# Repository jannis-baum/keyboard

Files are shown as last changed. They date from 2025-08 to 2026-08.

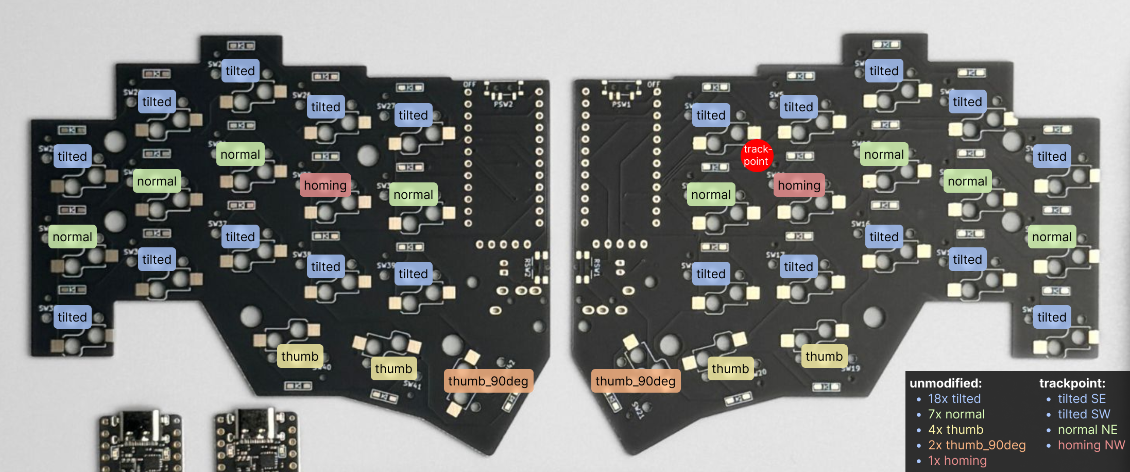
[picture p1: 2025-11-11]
hardware/keycaps/layout.png

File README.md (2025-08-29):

# Keyboard setup

I use a 36 key [Chocofi](https://github.com/pashutk/chocofi) keyboard with a [Sprintek SK8707-01 trackpoint](https://www.sprintek.com/en/products/pointing_stick/SK8707-01.aspx), made wireless with [nice!nano's](https://nicekeyboards.com/nice-nano).

This repo is where I keep my [ZMK firmware](https://zmk.dev) as well as my [Karabiner Elements](https://karabiner-elements.pqrs.org/) setup, and also the files to print the keyboard case & key caps.
Since I like having all my keybindings available on my laptop's built-in keyboard as well, most of the interesting stuff is implemented with Karabiner rather than ZMK.

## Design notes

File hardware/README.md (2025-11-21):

# Hardware parts

- printed:
    - keycaps are [KLP Lamé](https://github.com/braindefender/KLP-Lame-Keycaps/blob/76b0aec08eb0d98ea8802d6bd8cab8d96e1ae3f5), see [`LICENSE-keycaps`](LICENSE-keycaps)
    - case is derived from [official Chocofi case](https://github.com/pashutk/chocofi/blob/273676d11b06785fb5a1a94860a39fc36c38baba/case/v1/), see [`LICENSE-case`](LICENSE-case)
    - trackpoint extension is from [infused-kim/kb_trackpoint_extension](https://github.com/infused-kim/kb_trackpoint_extension/blob/6a5e8eec101584ba189b6014e04a38ebcbd04d82), see [`LICENSE-trackpoint-extension`](LICENSE-trackpoint-extension)
- electronics:
    - [Chocofi kit from beekeeb](https://shop.beekeeb.com/products/chocofi-low-profile-split-keyboard-diy-kit-nice-nano-wireless)
    - [SK8707-01 Trackpoint Sensor](https://www.sprintek.com/en/products/pointing_stick/SK8707-01.aspx)
    - [custom trackpoint connector PCB](./trackpoint-connector.zip)

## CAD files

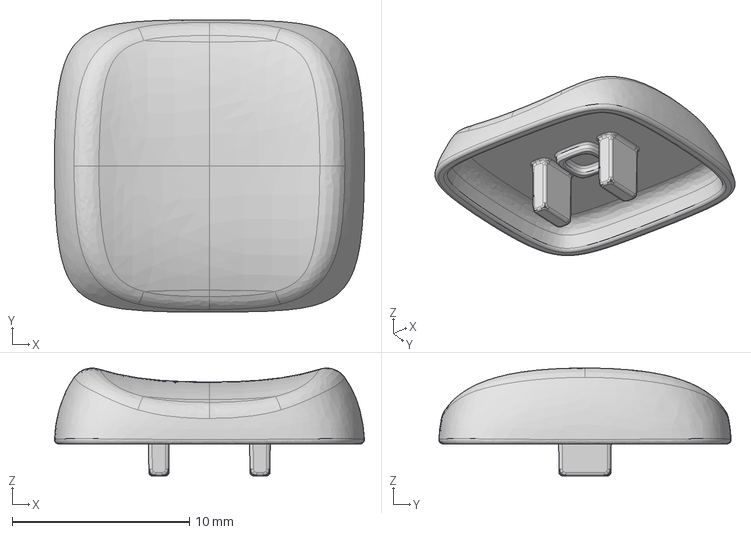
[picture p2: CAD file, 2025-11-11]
hardware/keycaps/step/normal.step
17.5 x 16.5 x 6.08 mm

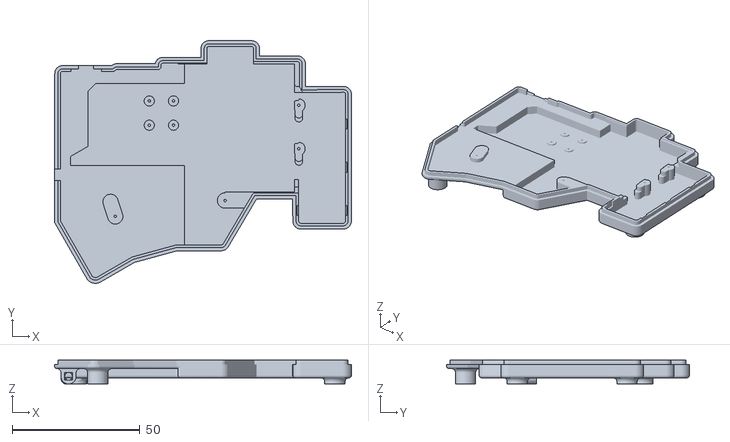
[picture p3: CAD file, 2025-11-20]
hardware/print/bottom-right.stl
116.5 x 95.2 x 9.40

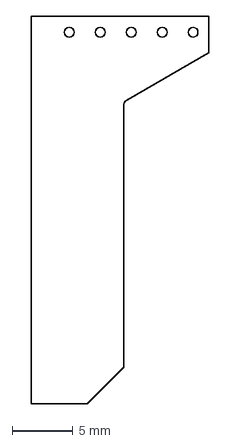
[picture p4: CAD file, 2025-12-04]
hardware/trackpoint-connector-shape.dxf
14.6 x 31.8 mm

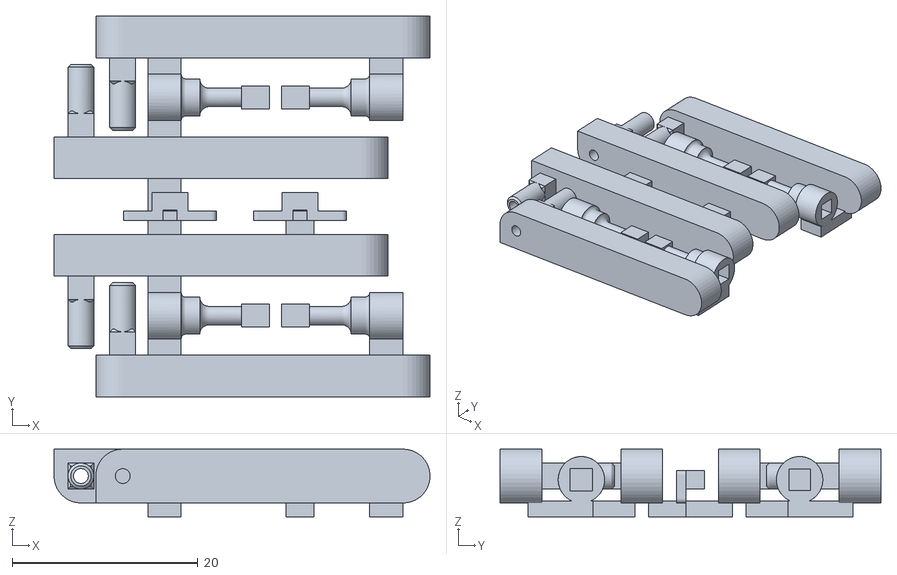
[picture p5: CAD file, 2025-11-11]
hardware/print/misc.stl
40.5 x 41.0 x 7.30

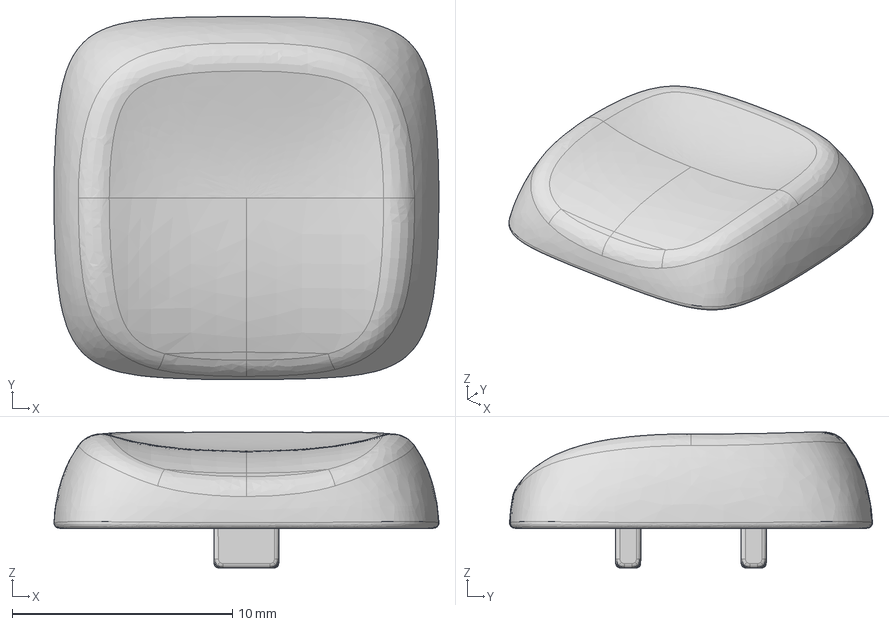
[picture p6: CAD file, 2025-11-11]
hardware/keycaps/step/thumb_90deg.step
17.5 x 16.5 x 6.17 mm

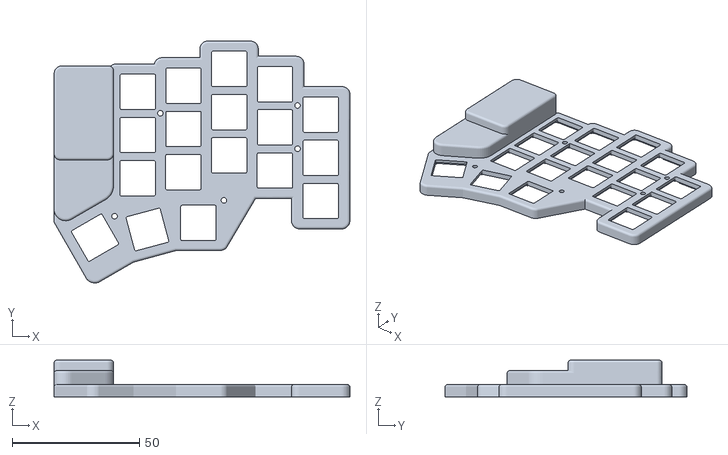
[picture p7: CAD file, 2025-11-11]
hardware/print/top-right.stl
116.5 x 95.2 x 14.4

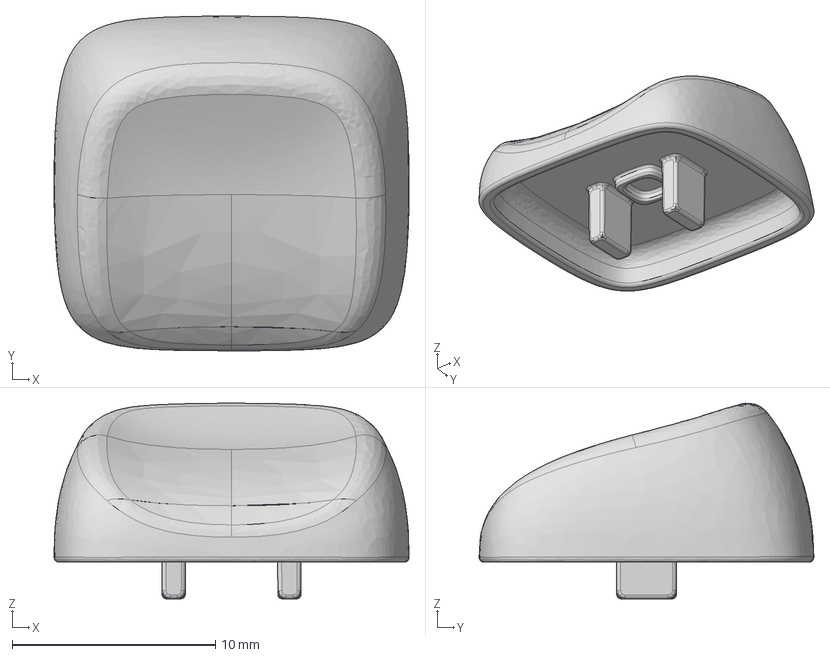
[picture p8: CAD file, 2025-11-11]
hardware/keycaps/step/tilted.step
17.5 x 16.5 x 9.63 mm

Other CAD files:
hardware/keycaps/step/homing.step
hardware/print/bottom-left.stl
hardware/keycaps/step/thumb.step
hardware/print/top-left.stl
hardware/keycaps/stl/homing.stl
hardware/keycaps/stl/normal.stl
hardware/keycaps/stl/thumb.stl
hardware/keycaps/stl/thumb_90deg.stl
hardware/keycaps/stl/tilted.stl

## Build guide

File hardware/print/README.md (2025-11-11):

# Printing

I printed the parts in the following quantities & materials at [JLC3DP](https://jlc3dp.com/):

| STL-file | quantity | method | material | notes |
| :-- | :-- | :-- | :-- | :-- |
| `top-left` | 1 | SLA | 8001 Resin (transparent)
| `top-right` | 1 | SLA | 8001 Resin (transparent)
| `bottom-left` | 1 | SLA | 8001 Resin (transparent)
| `bottom-right` | 1 | SLA | 8001 Resin (transparent)
| `keycaps-1` | 1 | SLA | 8001 Resin (transparent) | connected parts
| `keycaps-2` | 3 | SLA | 8001 Resin (transparent) | connected parts
| `misc` | 1 | MJF | PA12-HP Nylon | connected parts

The above is the requirement for exactly one keyboard.
To be safer I recommend printing one extra set for all the [connected parts](https://jlc3dp.com/help/article/Connected-Parts-Printing-Guide).

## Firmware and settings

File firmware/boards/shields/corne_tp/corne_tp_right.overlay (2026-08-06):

/*
 * Copyright (c) 2020 Pete Johanson
 *
 * SPDX-License-Identifier: MIT
 */

#include "corne_tp.dtsi"

&default_transform {
    col-offset = <6>;
};

&five_column_transform {
    col-offset = <6>;
};

&kscan0 {
    col-gpios
        = <&pro_micro 14 GPIO_ACTIVE_HIGH>
        , <&pro_micro 15 GPIO_ACTIVE_HIGH>
        , <&pro_micro 18 GPIO_ACTIVE_HIGH>
        , <&pro_micro 19 GPIO_ACTIVE_HIGH>
        , <&pro_micro 20 GPIO_ACTIVE_HIGH>
        , <&pro_micro 21 GPIO_ACTIVE_HIGH>
        ;
};


/*
 * PS/2 Mouse / Trackpoint - User Configuration
 *
 * Enable PS/2 drivers on this side of the keyboard.
 * It MUST be the central half. If you connected your TP or mouse to the
 * left side, then move the following content to `your_keyboard_left.overlay`
 *
 * You also need to adjust `Kconfig.defconfig` and configure that this side
 * is the central side.
 *
 */


// Pick the PS/2 driver
//
// Comment out the following define to use the PS/2 GPIO driver instead of the
// UART driver.
//
// Both, the UART and GPIO drivers, implement the PS/2 protocol and work with
// trackpoints and other mouse devices that use PS/2.
//
// The only difference is which hardware they use on your controller to
// transmit the data. The UART driver has MUCH better performance and should
// be used by most people.
//
// The GPIO driver should only be used if your PS/2 pointing device uses a
// clock frequency rate that is not compatible with the UART baud rates. Or
// if you are NOT using a nrf52-based controller, such as the nice!nano,
// nice!nano clone or a seeduino xiao.
//
// In all other cases you should try using the UART driver first.
#define MOUSE_PS2_DRIVER_UART


// Configure the SCL and SDA pins using the`&pro_micro` notation.
//
// If possible, try to choose the blue high frequency pins to avoid
// bluetooth interference.
//
// It will still work even if you pick low frequency pins, but there is a risk
// that the trackpoint could cause bluetooth interference.
//
// On the nice!nano documentation these are green DX pins:
// https://nicekeyboards.com/docs/nice-nano/pinout-schematic
//
// The ideal pins are...
//   - D1 and D0 for clock and data, because they are high frequency.
//   - D8, D9, D16 or D10 for the trackpoint reset pin, because it doesn't
//     need to be high frequency (only needed if you are not using a reset
//     circuit)
//
// But on the corne keyboard, these pins are used for the backlight. So, this
// example config uses the pins D16 and D10 for clock and data and
// D9 for the reset circuit.
#define MOUSE_PS2_PIN_SCL_PRO_MICRO <&pro_micro 2 GPIO_ACTIVE_HIGH>
#define MOUSE_PS2_PIN_SDA_PRO_MICRO <&pro_micro 3 GPIO_ACTIVE_HIGH>

// Configure the Power-On-Reset pin
//
// Uncomment and configure this pin if you have an extra free pin and want the
// controller to perform the Power-On-Reset sequence, which many trackpoints
// require.
//
// You don't need this if you are not using a trackpoint or if you have a
// trackpoint reset circuit.
//
// It's ok to use a low-frequency pin for this.
#define MOUSE_PS2_PIN_RST_PRO_MICRO <&pro_micro 0 GPIO_ACTIVE_HIGH>


// Configure SDA pin using the pinctrl notation
//
// Now configure SDA pin using the pinctrl notation. Make sure to use the same
// pin as in the pro micro notation, but convert it to the pinctrl notation.
//
// For the nice!nano you can find it on their pinout schematic, next to the
// pins, in the blue or violet boxes, with a format like `PX.YY` (P0.09).
//
// Enter it like `X, Y` without leading zeroes.
//
// Examples:
//      D1  - P0.06: 0, 6
// 		D0  - P0.08: 0, 8
//		D15 - P1.13: 1, 13
//		D16 - P0.10: 0, 10
//		D10 - P0.09: 0, 9
//
// We don't define the SCL pin, because UART uses a baud rate instead of
// a clock pin.
#define MOUSE_PS2_PIN_SDA_PINCTRL <NRF_PSEL(UART_RX, 0, 20)>
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

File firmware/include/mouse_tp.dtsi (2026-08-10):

#ifdef HAS_MOUSE_TP
  #include <dt-bindings/zmk/mouse.h>
  #include <dt-bindings/zmk/mouse_settings.h>
  #include <behaviors/mouse_keys.dtsi>
  #include <behaviors/mouse_setting.dtsi>

 /*
  * Key Behaviors to adjust settings
  */

  // They key codes below can be used to adjust the TP settings at runtime
  // without needing to recompile the firmware.
  //
  // The values will be logged and saved in the config on the controller flash
  // after 60s (CONFIG_ZMK_SETTINGS_SAVE_DEBOUNCE).
  //
  // On boot the settings will be restored again.
  //
  // If you prefer a more explicit way of configuration, you can also hardcode
  // these settings in `&mouse_ps2`.
  //
  // If you set these settings in `&mouse_ps2`, you will still be able to
  // adjust the values during runtime with these key codes, but after
  // restarting the board the values in `&mouse_ps2` will be restored and not
  // the ones stored in the flash using the key codes.


  // How sensitive the trackpoint is
  #define U_MSS_TP_S_I &mms MS_TP_SENSITIVITY_INCR
  #define U_MSS_TP_S_D &mms MS_TP_SENSITIVITY_DECR


  // The maximum speed the trackpoint will accelerate to
  #define U_MSS_TP_V6_I &mms MS_TP_VALUE6_INCR
  #define U_MSS_TP_V6_D &mms MS_TP_VALUE6_DECR


  // I am not quite sure tbh... default seems fine.
  #define U_MSS_TP_NI_I &mms MS_TP_NEG_INERTIA_INCR
  #define U_MSS_TP_NI_D &mms MS_TP_NEG_INERTIA_DECR


  // How hard you have to press to activate the "Press To Select" feature that
  // lets you tap or press on the trackpoint to click.
  //
  // Not all trackpoints support it and you have to enable
  // `tp-press-to-select;` in `&mouse_ps2` first.
  #define U_MSS_TP_PT_I &mms MS_TP_PTS_THRESHOLD_INCR
  #define U_MSS_TP_PT_D &mms MS_TP_PTS_THRESHOLD_DECR


  // If you mess up the settings, you can use this key code to clear the
  // settings from flash and re-set the default values on the TP.
  //
  // Make sure to wait at least CONFIG_ZMK_SETTINGS_SAVE_DEBOUNCE seconds (60
  // by default) before restarting the board to ensure the settings are
  // written to flash storage.
  #define U_MSS_RESET   &mms MS_RESET


  // If you prefer to set the settings in `&mouse_ps2`, you can use the key
  // codes above to find the settings you like the most and then press this
  // key code to output the settings to the log.
  //
  // Then you can add those values to `&mouse_ps2`
  #define U_MSS_LOG     &mms MS_LOG


  // Only apply these settings on the side that has the TP connected
  // (usually the right side)
  #ifdef MOUSE_PS2_DT_PRESENT

   /*
    * Input Listener Config
    */

    &mouse_ps2_input_listener {

      // Adjust pointing device axes.
      // This adjusts the values inside the zmk driver. Some
      // trackpoints also allow you to adjust it in their firmware. Check
      // the driver options below for more info.
      // xy-swap;
      // x-invert;
      // y-invert;

      // Set the layer that should automatically activate when the mouse is
      // moving.
      layer-toggle = <MOUSE_TP>;

      // How long the mouse needs to move for before the layer is activated (to
      // avoid accidental activations while typing) (Default: 250)
      layer-toggle-delay-ms = <300>;

      // How long to wait, after the last mouse movement, before deactivating
      // the layer (Default: 250)
      layer-toggle-timeout-ms = <400>;
    };


   /*
    * Mouse Driver Settings
    */

    &mouse_ps2 {

      // How sensitive the TP is (Default: 128)
      // tp-sensitivity = <128>;


      // The maximum mouse movement speed the TP will accelarate to
      // (Default: 97)
      // tp-val6-upper-speed = <97>;


      // Negative Inertia (Default: 6)
      // Makes the TP feel more responsive and "overshoot" less.
      // tp-neg-inertia = <6>;


      // Enable clicking by tapping on the TP.
      // Not all TPs support this.
      // tp-press-to-select;
      // tp-press-to-select-threshold = <10>;


      // Adjust axis settings on the TP
      // Works only on some trackpoints, but may be properly considered by the
      // trackpoint's acceleration features (which may or may not have an
      // impact).
      //
      // Alternatively consider achieving the same effect using the
      //  `input-listener` settings below.
      // tp-xy-swap;
      // tp-x-invert;
      // tp-y-invert;


      // Set sampling rate
      //
      // The frequency at which the mouse samples and sends data (in hz).
      // The default rate is 100. You can try lowering it if you experience
      // connection errors.
      //
      // Higher values than 100 are no improvement in my experience, but will
      // increase battery life and potentially errors in transmissions.
      //
      // These values are allowed: 10,20,40,60,80,100,200
      // sampling-rate = <60>;
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

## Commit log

2022-09-25 sleep & battery reporting
2022-12-05 increase BLE power
2025-08-29 feat: track sources in makefile
2025-09-08 fix: tab switching
2025-11-11 feat: add parts
    [bottom-left.stl, bottom-right.stl, misc.stl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]
2025-11-11 feat: add keycaps
    [homing.step, homing.stl, normal.step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]
2025-11-11 docs: add printing notes
2025-11-20 change: bottom right housing to accommodate connector pcb
    [bottom-right.stl]
2025-11-21 feat: add trackpoint connector pcb
2025-12-04 feat: add trackpoint connector pcb base shape
    [trackpoint-connector-shape.dxf]
2026-08-06 feat: switch to pinned forks
